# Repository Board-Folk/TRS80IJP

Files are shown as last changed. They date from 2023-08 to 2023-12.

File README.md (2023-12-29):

# TRS80IJP

A remake of the TRS-80 Model I Japanese (TEC) edition motherboard.

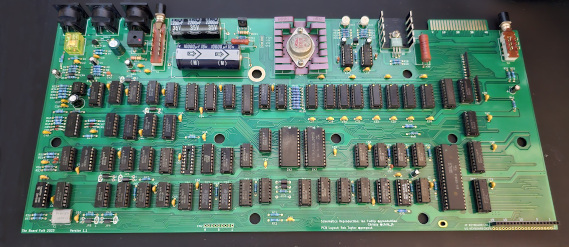
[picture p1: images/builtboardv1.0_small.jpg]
Built Board in Green


This reposistory contains the BOM, gerbers and Kicad files for a remake of the TEC, Japanese version of the TRS-80 Model I, and some related projects and files to help make it work.

The Japanese board is a rework of the original US edition, some components updated and extra jumpers added to configure the system for 50/60 Hz use, support for an extra character ROM a change to 2114 video RAM chips which are more readily available. The pinout for the Japanese keyboard is different. Because of this for the purposes of making the remake more useful we've added a second pin header for the connection of an original US keyboard. Note the keyboard headers have a 2.5mm pitch.

A replica of the original [TRS-80 Model I 1700069G board is now here](https://github.com/Board-Folk/TRS80IUS).

## Revisions

  * Version 1.1 Updated silkscreen including jumper tables for release.
  
## Version 1.1 Bill-of-Materials

All resistors 1/4W and capacitors 5mm pitch unless specified. Suggested substitutes might be wrong. Any feedback welcome.

|Qty|Reference(s)|Value|Type|Notes|
|:--:|:--:|:--:|:--:|:--:|
|2|R1, R32|100R|Resistor||
|1|R10|270R|Resistor||
|4|R11, R31, R34, R49|10K|Resistor||
|2|R12, R37|220R 1/2W|Resistor||
|1|R13|68 1/2W|Resistor||
|1|R14|2K7|Resistor||
|1|R15|750R|Resistor||
|1|R16|0R33 2W|Resistor||
|2|R17, R23|1K Potentiometer|Resistor||
|4|R2, R18, R19, R28|1K2|Resistor||
|1|R20|100K|Resistor||
|3|R21, R24, R25|3K3|Resistor||
|1|R22|1K5|Resistor||
|1|R26|2K2|Resistor||
|1|R27|12K|Resistor||
|1|R29|2K|Resistor||
|2|R3, R4|7K5|Resistor||
|1|R30|5R6 3W|Resistor||
|2|R33, R51|1M|Resistor||
|1|R35|680K|Resistor||
|1|R36|1.8M|Resistor||
|2|R38, R42|360K|Resistor||
|1|R39|10R|Resistor||
|17|R40, R41, R48, R54, R55, R64-R72, R74, R76, R77|4K7|Resistor||
|1|R43|560K|Resistor||
|5|R44-R47, R50|470K|Resistor||
|1|R5|220K|Resistor||
|2|R52, R53|8K2|Resistor||
|2|R56, R57|910R|Resistor||
|1|R6|75R|Resistor||
|1|R7|47R|Resistor||
|12|R8, R75, R101-R110|330R|Resistor||
|1|R9|120R|Resistor||
|2|RP1, RP2|4K7 Bussed SIP9|Resistor||
|2|C17, C18|220pF|Capacitor||
|44|C2, C8, C20, C22-C39, C41, C44-C49, C51-C59, C63-C69, C71, C72|100nF|Capacitor||
|4|C3, C7, C13, C15|10nF|Capacitor||
|1|C43|100pF|Capacitor||
|1|C60|47pF|Capacitor||
|1|C48|1nF|Capacitor||
|6|C1, C4, C6, C12, C14, C40|10uF 16V|Electrolytic Capacitor||
|1|C10|10000uF 16V|Electrolytic Capacitor||
|1|C19|100uF 16V|Electrolytic Capacitor||
|1|C5|220uF 16V|Electrolytic Capacitor||
|1|C70|22uF 16V|Electrolytic Capacitor||
|1|C9|2200uF 35V|Electrolytic Capacitor||
|3|C11, C16, C57|1nF|Film Capacitor|2.5mm|
|1|C50|2.7nF|Film Capacitor||
|1|CR1|S2V B20 Rectifier|Diode||
|1|CR2|1N4735A Zener|Diode||
|1|CR3|1N4733A Zener|Diode||
|1|CR4|1N4001|Diode||
|4|CR5, CR6, CR7, CR8|1N4148|Diode||
|1|Q1|2SC1815|Transistor||
|2|Q2, Q5|2SA1015|Transistor||
|1|Q3|2SC1499|Transistor||
|1|Q4|2SB-B531|Transistor|Suggested: MJ15016 (See links)|
|1|Q6|2SB-B595|Transistor|Suggested: MJE15029 (See links)|
|2|Z1, Z2|LM723|IC||
|1|Z11|74LS174|IC||
|2|Z12, Z23|74LS245|IC||
|8|Z15, Z16, Z17, Z18, Z19, Z20, Z21, Z22|4116 RAM|IC||
|4|Z24, Z30, Z59, Z66|74LS367|IC||
|1|Z25|LM3900N|IC||
|1|Z26|74LS14|IC||
|1|Z3|SN75452|IC||
|2|Z31, Z47|74LS132|IC||
|2|Z32|74C00|IC||
|2|Z44|74LS00|IC||
|3|Z33, Z46, Z50|74LS04|IC||
|2|Z37, Z38|MCM667X|IC|Character ROM(s) 1 required|
|1|Z39|74LS153|IC||
|2|Z4, Z56|74LS175|IC||
|3|Z40, Z64, Z67|74LS32|IC||
|1|Z41|74LS30|IC||
|1|Z42|2364 ROM|IC||
|1|Z43|2332 ROM|IC||
|2|Z45, Z54|74LS02|IC||
|1|Z48|Z80 DIP40 CPU|IC||
|2|Z49, Z68|74LS244|IC||
|1|Z5|74LS10|IC||
|2|Z51, Z52|74LS08|IC||
|3|Z53, Z62, Z63|74LS74|IC||
|1|Z55|74LS20|IC||
|2|Z57, Z58|74LS166|IC||
|2|Z6, Z65|74LS92|IC||
|1|Z60|74LS11|IC||
|1|Z61|74LS139|IC||
|4|Z7, Z28, Z34, Z35|74LS93|IC||
|6|Z8, Z13, Z14, Z27, Z29, Z36|74LS157|IC||
|2|Z9, Z10|2114 RAM|IC||
|2|CN1,CN3|19 pin header|Other|19 pins used on US|
|1|CN2|9 pin header|Other||
|3|J1-J3|DIN-5 180 Degree Socket|Other||
|10|JP1-JP10|Wire Links|Other||
|1|K1|5V Relay|Other|Suggestion/PN to Follow|
|1|S1|Power Switch|Other|Suggestion/PN to Follow|
|1|S2|Reset Switch|Other|Suggestion/PN to Follow|
|1|Y1|10.6445MHz HC49U|Other|(See links)|

## Notes on the Character ROM

The Japanese board has positions for two character ROMs. These are not regular ROMs.

The first, the original Motorola character ROM now almost unobtainable, on the original board is labelled with the part number 8046773. This is a masked rom programmed at the factory to the specs of Tandy, and is a variation of a stock ROM with a slightly modified character set. This ROM appears to be the same for both the Japanese and US versions of the board that we've seen.

The second character ROM we don't actually have adds a Kana character set which can be switched in and out by jumper setting, and apparently using the Japanese version of the keyboard. This would be fitted at position Z37, and isn't needed for the operation of the board.

The slightly more readily available MCM6674P character ROM can be used for either, but the character layout isn't compatible without modification by the BASIC ROM. If you need to use this we've created an adapter board (see the Extras folder) to modify the character map using an EPROM. Without it you'll end up with hieroglyphics ([see image](https://github.com/Board-Folk/TRS80IJP/blob/main/images/wrongmap.jpg)).

In addition to this, the good people of Tandy Discord have brought up that, way back when, the Gendon3 mod board was available as a substitute for the character ROM chip. This has proven suitable and usable for Japanese Model I though does require a single wired connection outside of the character ROM socket to work. We're currently testing versions of this a board that will fit original US version with a switch between two character sets as well as a board that will work with the built in Kana latch to switch between two character sets for the Japanese board. These have now been uploaded ot the Extras section, with a basic ROM set. More ROMs to use with them will be added as we find them. We're currently a bit stuck finding the Kana character set. There's enough there to get a system working without an original Motorola chip now if need be.

## Links

  [10.6445Mhz HC49U Quartz Crystal (UK)](https://www.mutant-caterpillar.co.uk/shop/product_info.php?products_id=5174)<br>
  [MJ15016 Transistor (Q4 Substitute) (UK)](https://www.cricklewoodelectronics.com/MJ15016.html)<br>
  [MJE15031 Transistor (Q6 Substitute) (UK)](https://www.cricklewoodelectronics.com/MJE15031.html)

## Credits

PCB Layout by Rob Taylor @peepouk. Schematics recreated by Ian Cudlip @grandoldian, and Chrissy @chris_jh.

## Thanks

  * The rest of the Board Folk Team
  * Adrian Black and friends for their test ROM which has been invaluable during testing. [TRS-80 Diagnostic ROM](https://github.com/misterblack1/trs80-diagnosticrom).

## Legal

As the product of this project is a replica of a proprietary product, the the author makes no claim of copyright to the schematics nor PCB layouts and releases these into the public domain, solely for the purposes of study and historical preservation.

You are free to produce PCBs based on this project's designs at your own risk and without limitation, for your own use or for sale and/or repair at a reasonable price. Attribution is appreciated. The authors are not obliged to provide support of any kind. 

Under no circumstances will the authors be held responsible or liable in any way for losses, damages or costs resulting from the use of the information and/or resources of this project. 

The resources are provided "as-is" without warranty of any kind, either expressed or implied, including, but not limited to, the implied warranties of merchantability and fitness for a particular purpose.

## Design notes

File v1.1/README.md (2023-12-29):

# TRS80IJP Gerbers, iBOM and Kicad files

v1.1 Initial Public Release

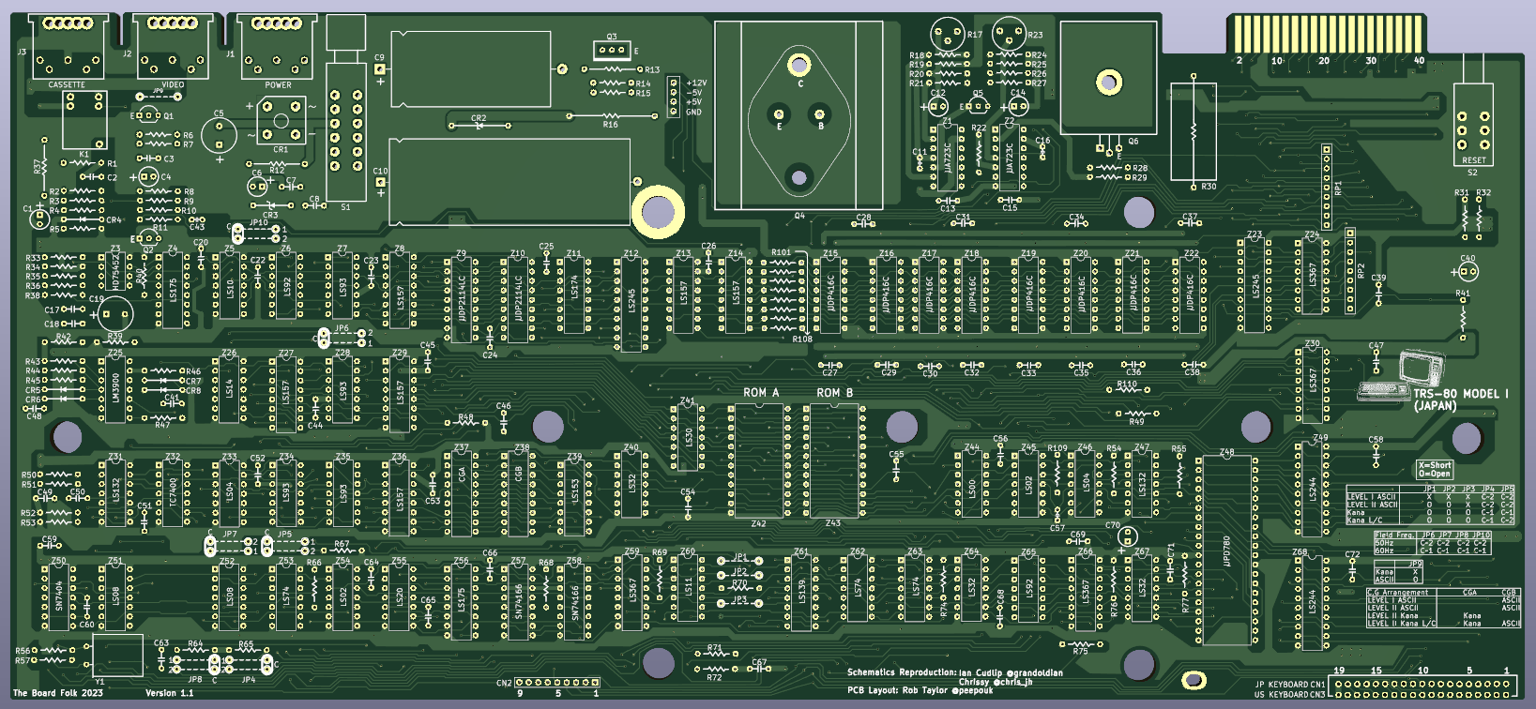
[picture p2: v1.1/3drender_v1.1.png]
3D Render of v1.1 Board


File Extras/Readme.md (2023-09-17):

# TRS80IJP Extras

## Inventory

### Charmap

TRS-80 Model I Character Map Adapter Board for MCM6674P 

### TRSG3Mod

Two versions of an updated character ROM substitute board based on the original Gendon3 Mod board that uses an 2716 or 2532 EPROM to provide the character set without an original Motorola chip. Requires a soldered wire connection not provided by the character ROM socket.

## To follow

  * 32K RAM Expansion Board
  * PS/2 Keyboard Adapter

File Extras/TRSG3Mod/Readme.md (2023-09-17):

# G3Mod and G3JPMod Character ROM Substitute Boards

Two versions of an updated character ROM substitute board based on the original Gendon3 Mod board that uses an 2716 or 2532 EPROM to provide the character set without an original Motorola chip. They require a soldered wire connection not provided by the character ROM socket.

Both boards allow the use of a 2716 2KByte EPROM to provide a single character set to the system, or a 2532 EPROM to provide two selectable 2KByte alternative ROM images.

Each board provides two pin connections, the first of which needs to be connected to L8 on an unmodified TRS-80 Model I for the board to work as standard. The second pin same as provided by the original Gendon3 is out of the scope of this project at this time.

Not suitable for a 2732 EPROM as the pinout's slightly different for the upper 2K. Might do other versions of these if needed, but have found the Hitachi HN462532G 2532 chips readily available new so haven't as yet.

## TRSG3Mod

The first board, G3Mod is primarily intended for use on the original US TRS-80 Model I (physical layout) and has a switch to select between the two 2K halves of the EPROM. 

Pin 1 wire connection should be to Z12 pin 11, on an original US board, and Z35 pin 11 on a Japanese board.

The BOM is simple, just a 0805 or 0402 10K resistor if you want to use the selector switch, the switch which itself, a standard single SPST 2.54mm pitch DIP, a coupling wire to the connection point and the 24 pin EPROM itself. It's nice to put it in a socket for reprogramming. To just use the first half of the 2532 without a switch put a solder blob over the 0402 position.

## TRSG3JPMod

The second board, G3JPMod is intended for use with the Japanese TRS-80 Model I, the two halves of the ROM being selected either by jumper settings on the main board, or by keyboard selection.

Pin 1 wire connection should be to Z35 pin 11.

Just requires a coupling wire to the connection point and the 24 pin EPROM itself with a socket if need be.

## ROMS

ROM images for both boards. More to follow.

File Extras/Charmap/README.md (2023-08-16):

# TRS-80 Model I Character Map Adapter Board

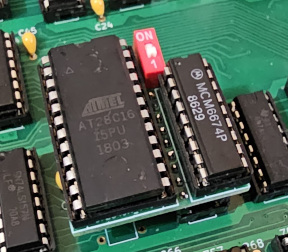
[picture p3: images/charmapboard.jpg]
Board with an EEPROM, MCM6674P Character ROM and a single position switch


The original masked TRS-80 character ROM is now difficult to obtain. This is a simple adapter board to allow the use of the more readily available MCM6674P character ROM with the TRS-80 Model I BASIC ROM, possibly others too with the right map. It uses a standard 24 pin EEPROM/EPROM to map the original address lines coming in to alternatives compatible with your available character ROM to create the correct video output. Without it BASIC will give you garbage ([see image](https://github.com/Board-Folk/TRS80IJP/blob/main/images/wrongmap.jpg)).

The character ROM itself is a 7 bit ROM giving 128 characters. The character map a simple byte array providing the location of the alternative character of the replacement character in the substitute ROM used for each position.

The map board incorporates a single two position switch to allow the EPROM to be programmed with two alternative maps - two lots of 128 bytes which are positioned at the start of the EPROM.

The Kicad project for the board is in the Kicad folder with the zip file TRS80I-Charmap-Gerberv1.zip being the Gerber of this project. The file out.rom is my interpretation of how the MCM6674P should be represented to BASIC and this was generated using the C code trs80map.c. Please feel free to make your own maps. :-)

I've used an Atmel 28C16 as it's easy to re-flash.

## Credits

By Ian Cudlip @grandoldian November 2022.

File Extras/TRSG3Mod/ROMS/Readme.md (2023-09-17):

# G3Mod and G3JPMod Character ROM Substitute Board ROM Images

ROM images for use with the two ROM substitute boards. More images to follow. We still need to find a Kana character set!

## TRS80I_Short1_2k.bin

2KB image suitable for the TRS-80 Model I with shortened decenders to fit the character matrix.

## Gendon3_2k.bin

2KB image perceived as the primary image of the original Gendon3. This has long decenders that don't quite fit the TRS-80 Model I matrix size.

## TRS80IShort_Gendon3_4k.bin

4KB image for testing the image selection function with a 2532 EPROM. First half is TRS80I_Short1_2k.bin, second half Gendon3_2k.bin. Better images to follow.

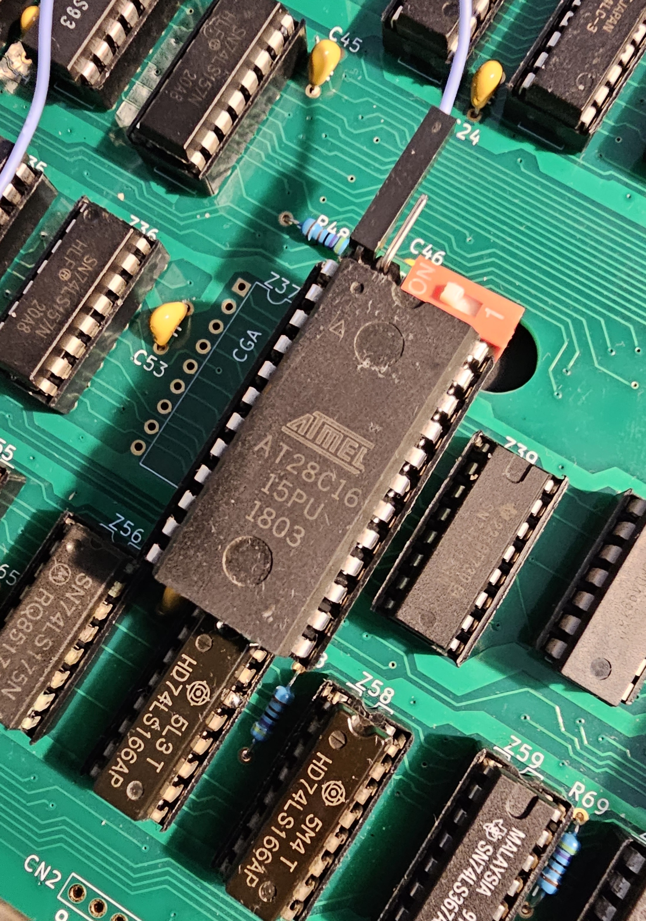
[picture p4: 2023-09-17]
Extras/TRSG3Mod/images/g3modv1_large.jpg

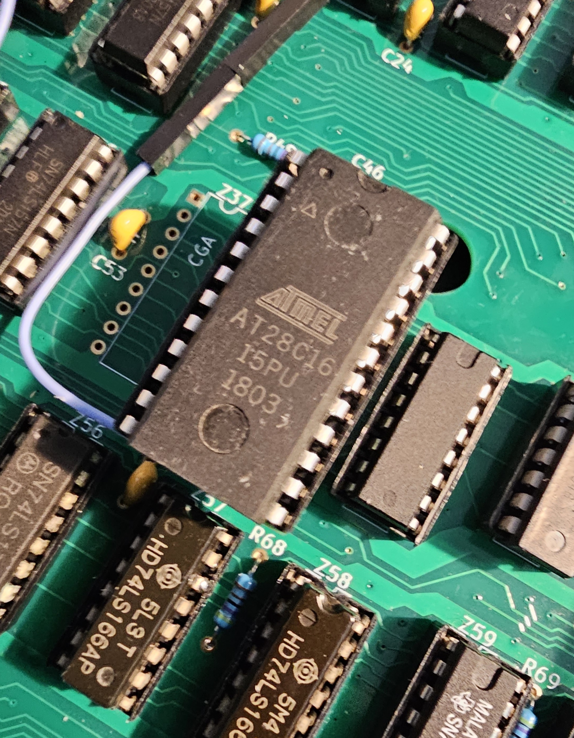
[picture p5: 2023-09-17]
Extras/TRSG3Mod/images/g3jpmodv1_large.jpg

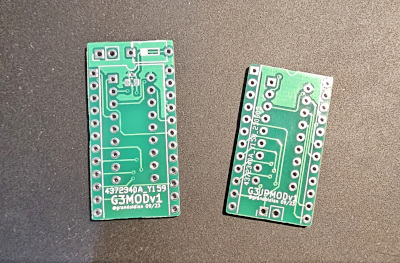
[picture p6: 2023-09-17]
Extras/TRSG3Mod/images/g3modboards_small.jpg

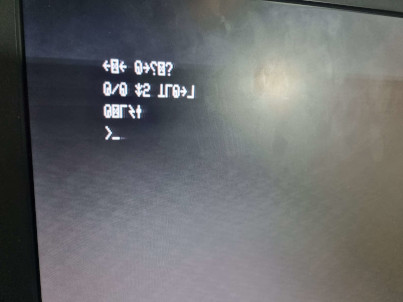
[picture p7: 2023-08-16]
images/wrongmap.jpg

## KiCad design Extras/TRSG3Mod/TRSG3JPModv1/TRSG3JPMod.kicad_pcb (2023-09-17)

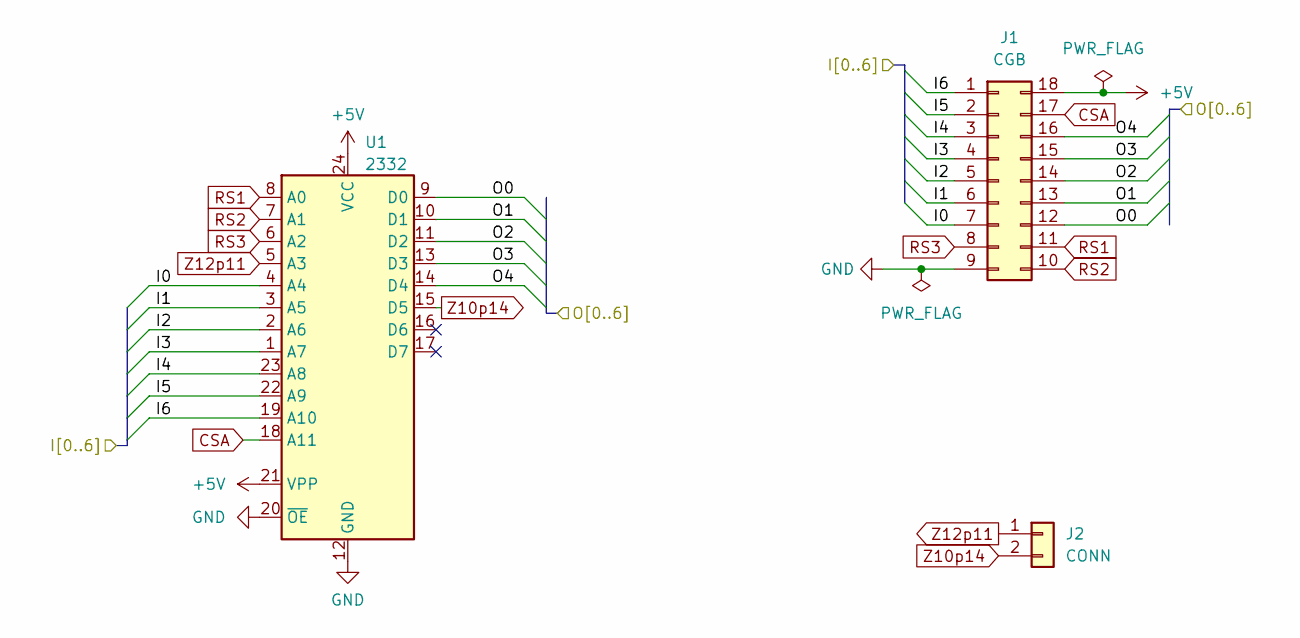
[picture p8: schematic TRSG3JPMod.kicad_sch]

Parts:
J1: CGB; CHARPLUG
J2: CONN; PinHeader_1x02_P2.54mm_Vertical
U1: 2332; DIP-24_W15.24mm

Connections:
+5V: J1.18, U1.21 (VPP), U1.24 (VCC)
/I0: J1.7, U1.4 (A4)
/I1: J1.6, U1.3 (A5)
/I2: J1.5, U1.2 (A6)
/I3: J1.4, U1.1 (A7)
/I4: J1.3, U1.23 (A8)
/I5: J1.2, U1.22 (A9)
/I6: J1.1, U1.19 (A10)
/O0: J1.12, U1.9 (D0)
/O1: J1.13, U1.10 (D1)
/O2: J1.14, U1.11 (D2)
/O3: J1.15, U1.13 (D3)
/O4: J1.16, U1.14 (D4)
CSA: J1.17, U1.18 (A11)
GND: J1.9, U1.12 (GND), U1.20 (~OE)
RS1: J1.11, U1.8 (A0)
RS2: J1.10, U1.7 (A1)
RS3: J1.8, U1.6 (A2)
Z10p14: J2.2, U1.15 (D5)
Z12p11: J2.1, U1.5 (A3)

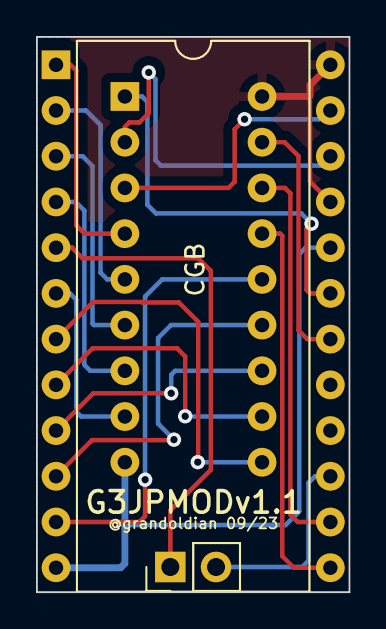
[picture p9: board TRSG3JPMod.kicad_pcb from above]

Board: 2 copper layers, 17.4 x 30.9 mm, 4 parts (1 on the bottom side), 20 nets.

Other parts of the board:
G1: LOGO8; BF8

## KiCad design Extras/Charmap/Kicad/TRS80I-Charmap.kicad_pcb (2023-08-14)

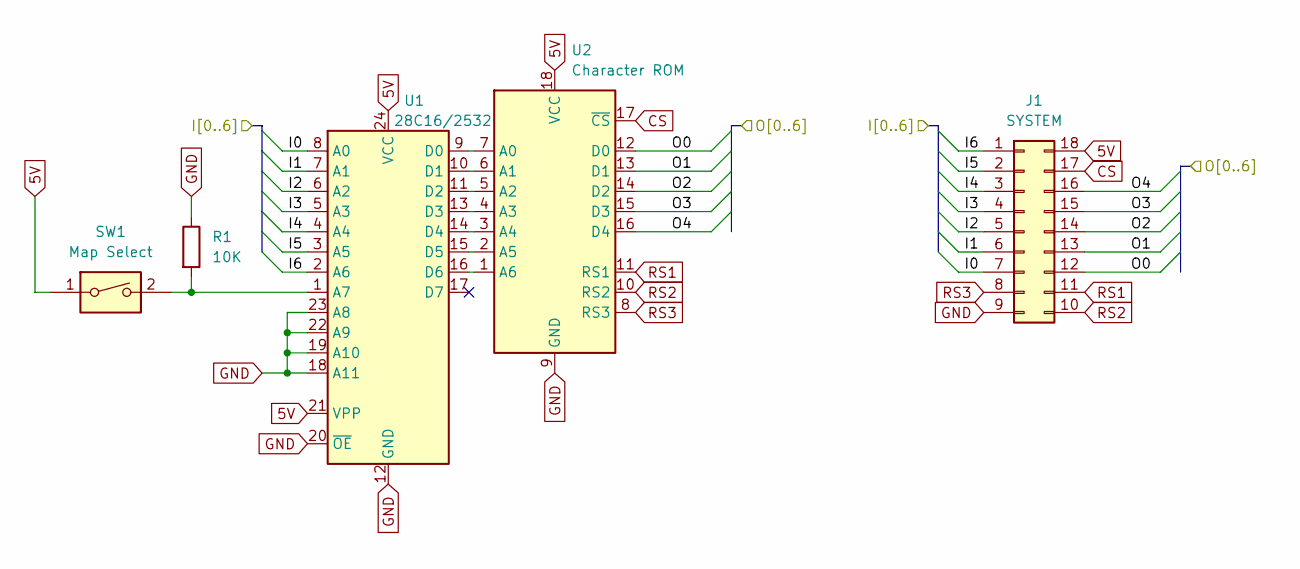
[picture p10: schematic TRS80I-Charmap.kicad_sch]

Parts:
J1: SYSTEM; DIP-18_W7.62mm
R1: 10K; R_0805_2012Metric
SW1: Map Select; SW_DIP_SPSTx01_Slide_6.7x4.1mm_W7.62mm_P2.54mm_LowProfile
U1: 28C16/2532; DIP-24_W15.24mm_Socket
U2: Character ROM; DIP-18_W7.62mm_Socket

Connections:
5V: J1.18, SW1.1, U1.21 (VPP), U1.24 (VCC), U2.18 (VCC)
/I0: J1.7, U1.8 (A0)
/I1: J1.6, U1.7 (A1)
/I2: J1.5, U1.6 (A2)
/I3: J1.4, U1.5 (A3)
/I4: J1.3, U1.4 (A4)
/I5: J1.2, U1.3 (A5)
/I6: J1.1, U1.2 (A6)
/O0: J1.12, U2.12 (D0)
/O1: J1.13, U2.13 (D1)
/O2: J1.14, U2.14 (D2)
/O3: J1.15, U2.15 (D3)
/O4: J1.16, U2.16 (D4)
CS: J1.17, U2.17 (~CS)
GND: J1.9, R1.1, U1.12 (GND), U1.18 (A11), U1.19 (A10), U1.20 (~OE), U1.22 (A9), U1.23 (A8), U2.9 (GND)
unnamed: R1.2, SW1.2, U1.1 (A7)
unnamed: U1.9 (D0), U2.7 (A0)
unnamed: U1.10 (D1), U2.6 (A1)
unnamed: U1.11 (D2), U2.5 (A2)
unnamed: U1.13 (D3), U2.4 (A3)
unnamed: U1.14 (D4), U2.3 (A4)
unnamed: U1.15 (D5), U2.2 (A5)
unnamed: U1.16 (D6), U2.1 (A6)
RS1: J1.11, U2.11 (RS1)
RS2: J1.10, U2.10 (RS2)
RS3: J1.8, U2.8 (RS3)

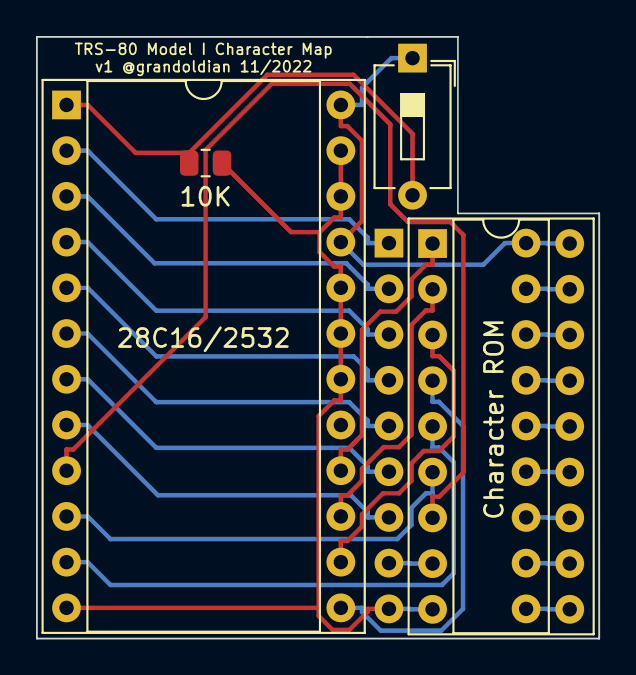
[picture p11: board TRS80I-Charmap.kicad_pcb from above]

Board: 2 copper layers, 31.2 x 33.4 mm, 5 parts (0 on the bottom side), 26 nets.

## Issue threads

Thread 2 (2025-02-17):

PCB Silkscreen Incorrect

kiwisincebirth, 2025-02-17:
I believe the silkscreen to be incorrect. regarding Jumper placement

The silkscreen on the PCB says:
* X = Short
* 0 = Open

From the technical reference Manual:
* X indicates without jumper wire.
* 0 indicates with jumper wire connected.

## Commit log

2023-08-14 Initial Update
    [TRS80I-Charmap.kicad_pcb, TRS80I-Charmap.kicad_sch]
2023-08-20 Publish Kicad/BOM
    [TRS80IJP_1.kicad_sch, TRS80IJP_CPU.kicad_sch, TRS80IJP_KEYBOARD.kicad_sch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]
2023-08-20 Remove some old
    [TRS80IJP_1.kicad_sch, TRS80IJP_CPU.kicad_sch, TRS80IJP_KEYBOARD.kicad_sch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]
2023-09-17 Large G3 Mod Board Images
2023-09-17 Upload G3Mod & G3JPMod
    [TRSG3JPMod-B_Cu.gbr, TRSG3JPMod-B_Mask.gbr, TRSG3JPMod-B_Paste.gbr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]
2023-09-17 Update TRSG3JPMod and Images
    [TRSG3JPMod-B_Cu.gbr, TRSG3JPMod-B_Mask.gbr, TRSG3JPMod-B_Paste.gbr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]
2023-09-25 Update Z32 label, Sync v1.1 Schematic to PCB
    [TRS80IJP_CPU.kicad_sch, TRS80IJP_KEYBOARD.kicad_sch, TRS80IJP_POWER.kicad_sch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]
